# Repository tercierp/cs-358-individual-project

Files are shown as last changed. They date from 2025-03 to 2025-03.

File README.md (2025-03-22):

# 2D Plotter Project

## Overview
This project showcases the development of a **2D plotter**, a machine capable of drawing complex fractal patterns using **L-systems**. The plotter consists of two stepper motors controlling the X and Y axes, along with a servo motor to lift and lower the pen. The software is written in **C++ for Arduino UNO**, which controls the motors and processes L-system instructions to generate fractals.

The goal of this project was to design and build a fully functional **pen plotter** that can create intricate mathematical patterns on a piece of paper. This work highlights my expertise in **embedded systems, motion control, algorithmic drawing, and mechanical design**. 

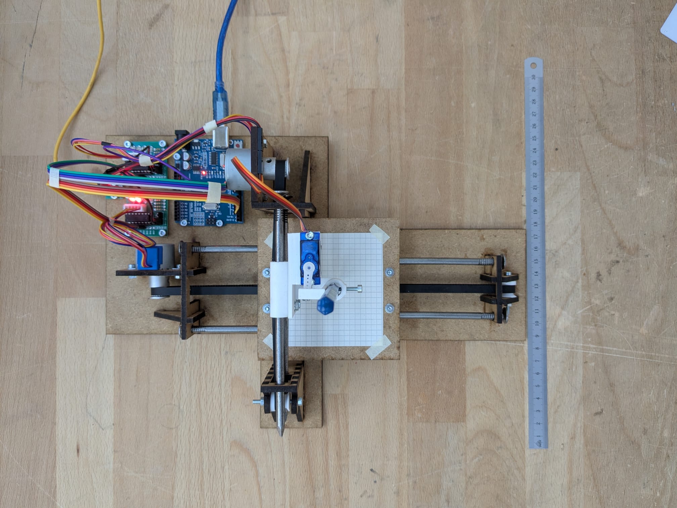
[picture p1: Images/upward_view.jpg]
Plotters

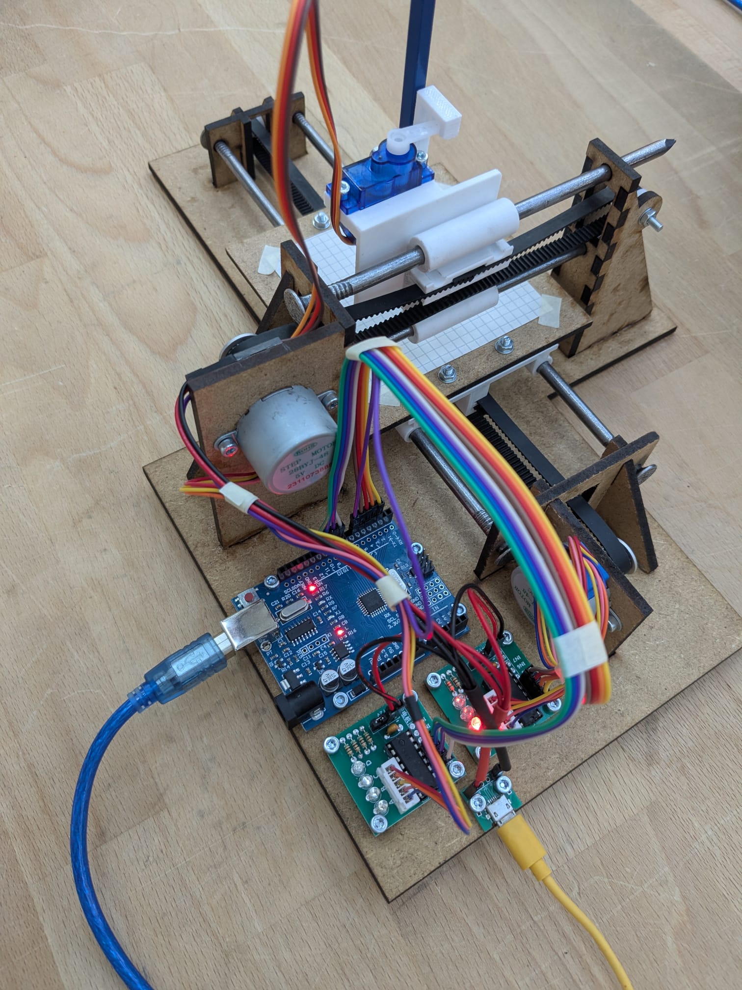
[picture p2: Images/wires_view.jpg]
wires


### Key Features
- **Stepper motors** for precise X-Y axis movement.
- **Servo motor** for lifting/lowering the pen.
- **Arduino UNO** for motor control.
- **L-System fractal generation** for drawing complex structures.
- **Laser-cut frame** for efficient manufacturing.
- **Pen holder 3D printing** for a precise design.

### Circuit
For good cable management, I created this circuit using Fritzing. For better understanding, the colors match the real cables in the pictures.
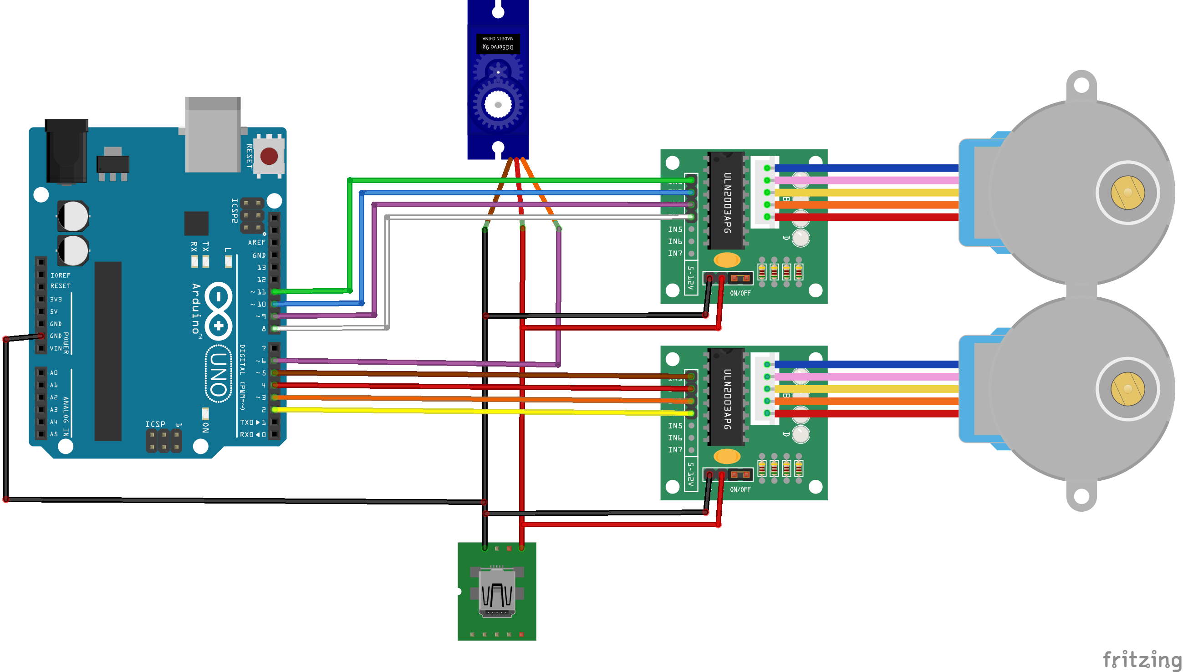
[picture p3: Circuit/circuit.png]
circuit


## Project Structure
### **Main code**
The core Arduino code for controlling the plotter is located in the **Code/** directory. This includes:
- circleinsidesquare.ino - Draw a circle and circle.
- L_System.ino - Implements L-system fractal parsing.
### **Debugging code**
- moveto.ino - Controls the position of the pen.
- servo.ino - Tests the positions of the servo.
- square.ino - Basic square.
- circle.ino - Basic circle.
- line.ino - Basic line.

## L-System Fractals
The plotter can generate various L-System fractals. Below are the corresponding input rules and parameters:
### Moore curve
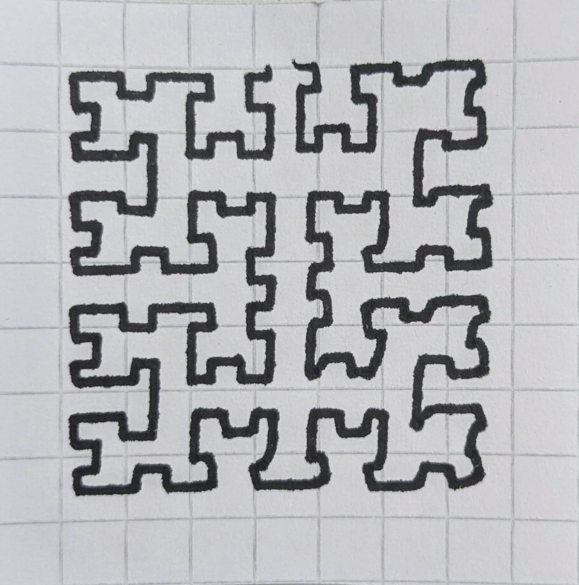
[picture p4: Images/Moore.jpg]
Moore curve

```
3;90;100;F;LFL+F+LFL;L=-RF+LFL+FR-;R=+LF-RFR-FL+
```
### Gosper curve
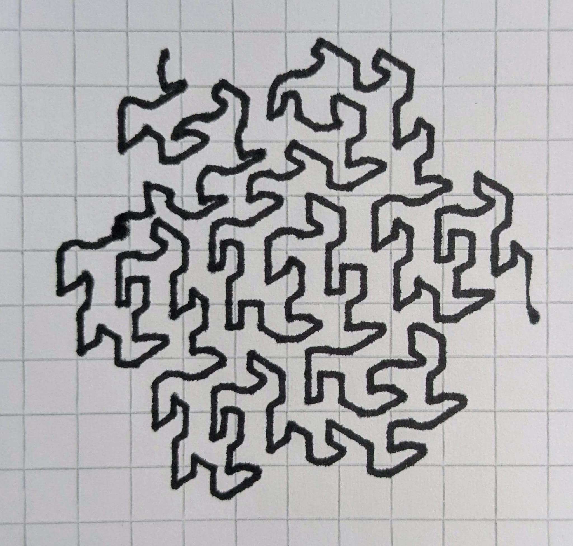
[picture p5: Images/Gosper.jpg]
Gosper curve

```
3;60;100;AB;A;A=A-B--B+A++AA+B-;B=+A-BB--B-A++A+B
```
### Dragon curve
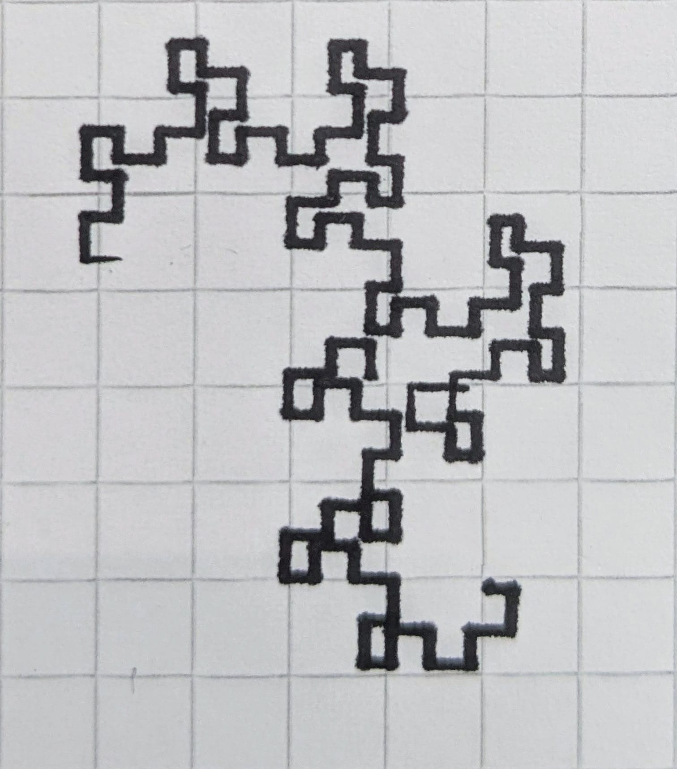
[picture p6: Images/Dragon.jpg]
Dragon curve

```
7;90;100;F;FA;A=A+BF+;B=-FA-B
```
### Koch curve
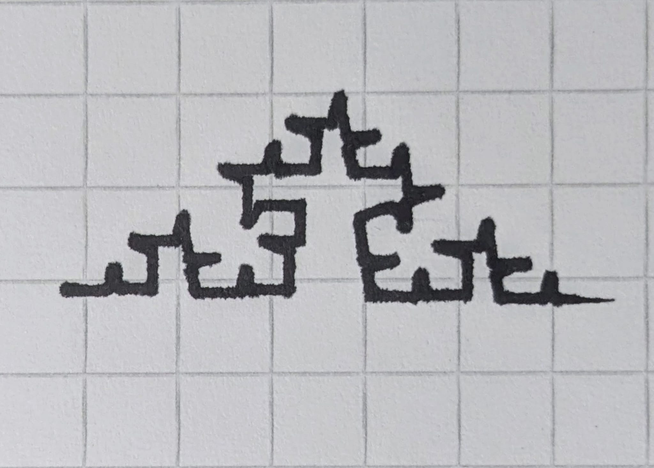
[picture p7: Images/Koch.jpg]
Koch

```
3;80;100;F;F;F=F+F--F+F;B=-FA-B
```
### Sierpinski Triangle
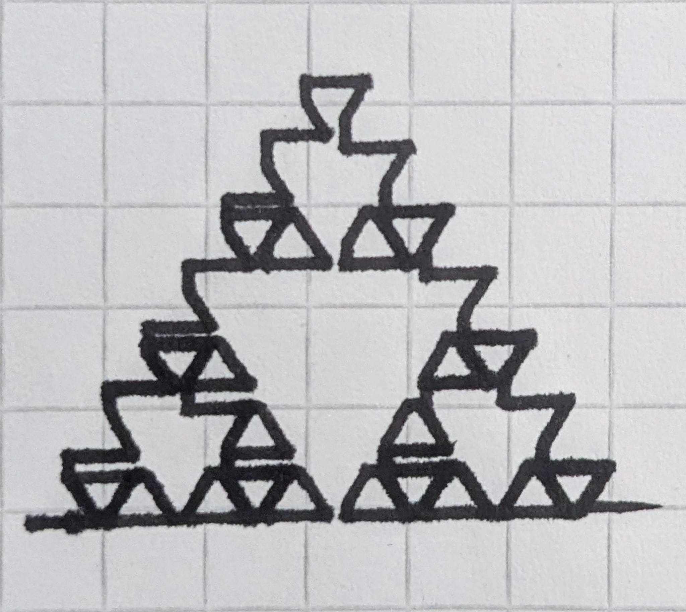
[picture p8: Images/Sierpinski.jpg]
Sierpinski Triangle

```
3;120;100;F;F;F=+F+F-F-F+F-
```

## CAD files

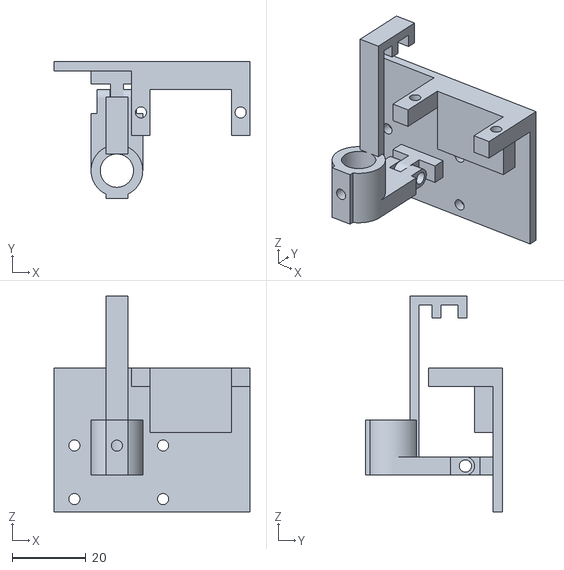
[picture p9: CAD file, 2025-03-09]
penholderv3.2.stl
53.0 x 37.0 x 58.5

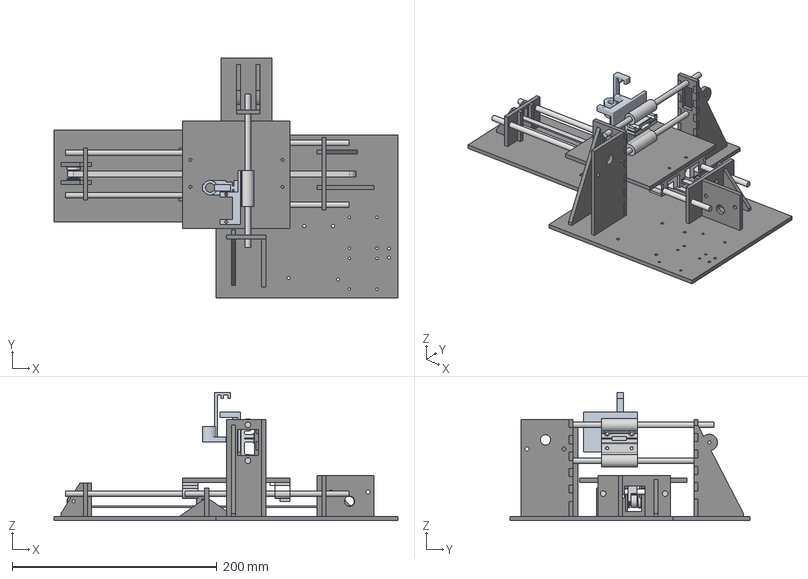
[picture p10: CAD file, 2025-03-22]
Plan_3D/2024-spring-2d-my-plotter.step
336.0 x 234.0 x 125.5 mm
TopRailHolder
BottomRailHolder
RightRailHolder
LeftRailHolder
MiddleHolder
PlateHolderNarrow
BasePlankNew
PenHolderSlider
Draw plate
Belt
PlateHolderWide
BlindPulley
Nails
part_object_id_1

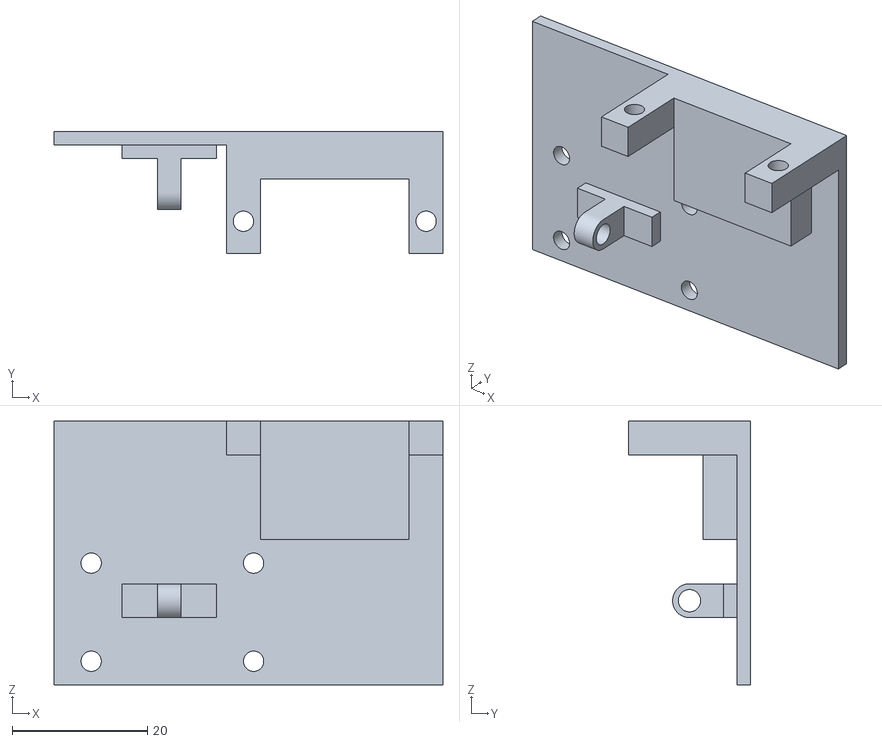
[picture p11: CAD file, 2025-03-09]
penholderv3.stl
57.5 x 18.0 x 39.0

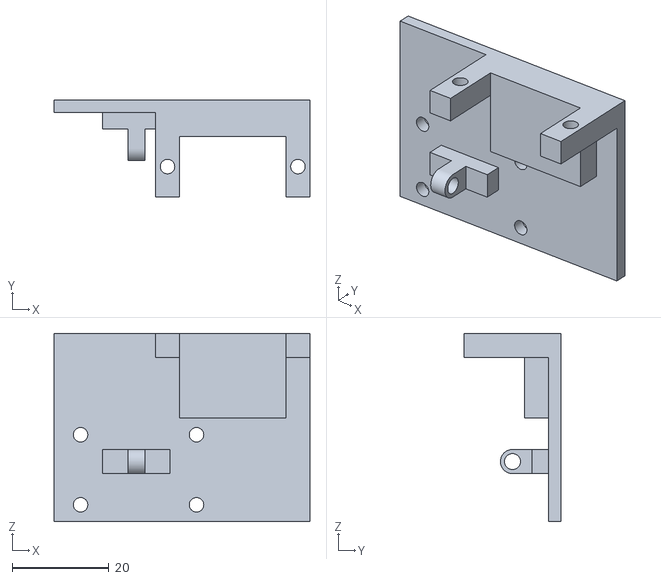
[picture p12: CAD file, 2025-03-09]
Plan_3D/penholder_back.stl
53.0 x 20.0 x 39.0

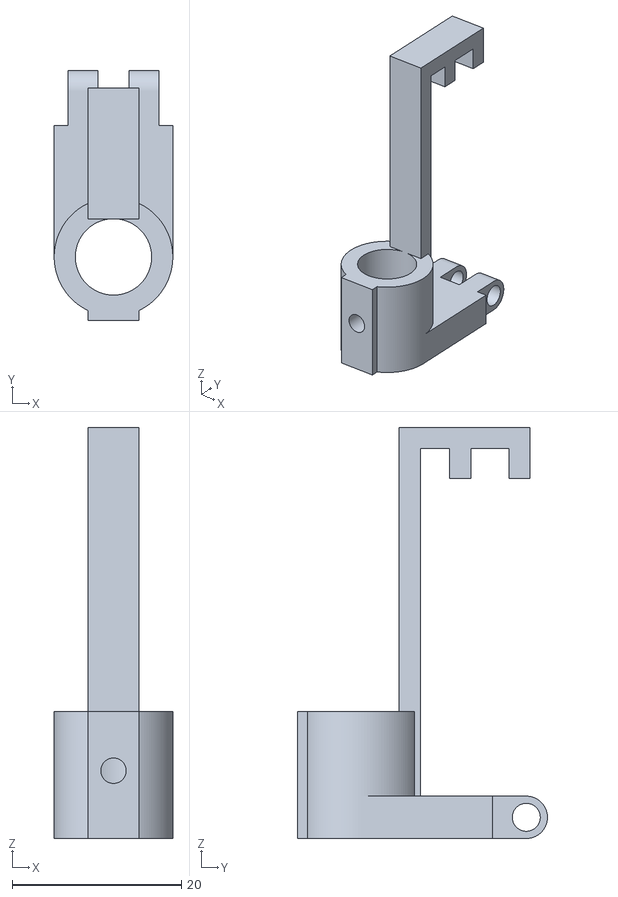
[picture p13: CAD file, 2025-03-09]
Plan_3D/penholder_front.stl
14.0 x 29.5 x 48.5

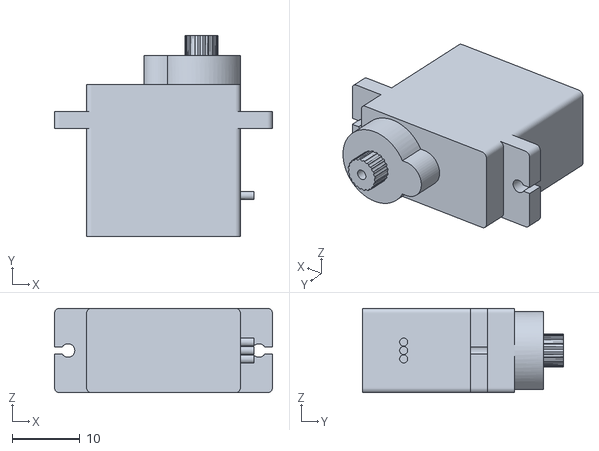
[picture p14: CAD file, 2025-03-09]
Plan_3D/stepper.stl
32.2 x 29.8 x 12.5

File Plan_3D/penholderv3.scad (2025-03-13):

$fn=128;
eps=0.01;
driftstepper=4.5;

//color("red") translate([41.5-driftstepper,-12.5/2-5,34]) rotate([-90,180,0]) import("stepper.stl", convexity=3);


module trou(d1,ep) {
    cylinder(h=ep+2*eps,d=d1,center=true);
}

module plot(ep) {
    translate([10.04,-ep,9.95]) difference() {
        union() {
             
            translate([0,-1,0])cube([14,5.5,5]);
            translate([7-3.5/2,-5,0]) cube([3.5,5+ep,5]);
            translate([7,-5,5/2]) rotate([90,0,90]) cylinder(h=3.5,d=5,center=true);
        
        
        }
        translate([7,-5,5/2]) rotate([90,0,90]) cylinder(h=3.5+2*eps,d=3.3,center=true);
    }
}

module plaque() {
    la = 57.5;
    lo = 39;
    ep = 2.5;
    av = 18;
    ls = 5;
    es = 5;
    motordeep=2;
    difference() {
        union() {
            cube([la-driftstepper,ep,lo]);
            translate([25.5-driftstepper,-av+0.5,lo-es]) cube([ls,av+motordeep,es]);
            translate([25.5+22+ls-driftstepper,-av+0.5,lo-es]) cube([ls,av+motordeep,es]);
            translate([30.5-driftstepper,-5,lo-17.5]) cube([22,7,17.5]);
            //color("green") translate([25.5+2.5,-12,33]) cube([27,1,1])
            plot(ep);
            
        }
        //trous
        translate([5.5,0,3.5]) translate([0,ep/2,0]) rotate([90,0,0])  trou(3,ep);
        translate([5.5+24.004,0,3.5]) translate([0,ep/2,0]) rotate([90,0,0])  trou(3,ep);
        translate([5.5+24.004,0,3.5+14.5]) translate([0,ep/2,0]) rotate([90,0,0])  trou(3,ep);
        translate([5.5,0,3.5+14.5]) translate([0,ep/2,0]) rotate([90,0,0])  trou(3,ep);
        translate([25.5+ls/2-driftstepper,-12.5/2-5,lo-es/2]) trou(3,es);
        translate([25.5+22+ls+ls/2-driftstepper,-12.5/2-5,lo-es/2]) trou(3,es);    
    }
}
//==============

module front(){
    //color("yellow")translate ([10,0,39])cube([1,1,motorh]);
    ox = 17;
    oy = -27;
    oz = 9.95;
    h = 48.5;
    m=11.45;
    platic=12.7;
    motorh=15.4;
    translate([ox,oy,oz]) union(){
        difference(){
            union() {
                
                translate ([0,0,7.5]) cylinder(h=15,d=14,center=true);
                translate ([-3,4.5,0])cube([6,2.5,h]);
                translate ([-3,-7.5,0])cube([6,2.5,15]);
                translate ([-7,0,0])cube([14,15.5,5]);
                //rotate([0,0,90])color("green")translate ([13.8,-12,43.5])cube([4,12.7,1.6]); 
                translate ([-3,4.5,h-2.5])cube([6,m+4,2.5]);
                translate ([-3,m+5+1,h-6])cube([6,2.5,4.5]);
                translate ([-3,m+5-6,h-6])cube([6,2.5,4.5]);
                
                
                
            difference() {
                union() {
             
                    translate([3.5+0.1-1.75,17-1-3,0]) cube([3.5,2.5+1+3,5]);
                    translate([3.5+0.1,2.5+17,5/2]) rotate([90,0,90]) cylinder(h=3.5,d=5,center=true);
        
        
                }
                translate([3.5+0.1,2.5+17,5/2]) rotate([90,0,90]) cylinder(h=3.5+2*eps,d=3.3,center=true);
            }
                
                
            difference() {
                union() {
                    translate([-3.5-0.1-1.75,17-1-3,0]) cube([3.5,2.5+1+3,5]);
                    translate([-3.5-0.1,2.5+17,5/2]) rotate([90,0,90]) cylinder(h=3.5,d=5,center=true);
        
                }
                translate([-3.5-0.1,2.5+17,5/2]) rotate([90,0,90]) cylinder(h=3.5+2*eps,d=3.3,center=true);
            }    
                
                }
            union() {  
                translate ([0,0,7.5]) cylinder(h=15+2*eps,d=9,center=true);
                translate ([0,-5,8])rotate([90,0,0])trou(3,5);
                
            }
        }
    }
}



front();
plaque(); 

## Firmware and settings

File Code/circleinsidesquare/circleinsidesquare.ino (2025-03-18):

#include <Servo.h>
#include <AccelStepper.h>
#include <MultiStepper.h>

#define MotorInterfaceType 4

// Servo setup
Servo servo;
int angle = 90;
int delta = 3;

// Define stepper motors with new pins
AccelStepper X(MotorInterfaceType, 2, 4, 3, 5);
AccelStepper Y(MotorInterfaceType, 8, 10, 9, 11);
MultiStepper XY;

// Position array for movement
long pos_xy[2] = {0, 0};

void setup() {
    // Initialize servo and set to initial (pen up) position
    servo.attach(6);
    penup(); // Ensure the pen starts in the up position

    // Set up stepper motors
    X.setMaxSpeed(400.0);
    Y.setMaxSpeed(400.0);
    XY.addStepper(X);
    XY.addStepper(Y);

    Serial.begin(9600);
    Serial.println("Enter square size:");
}

void loop() {
    penup(); // Keep pen up while waiting for input

    // Wait for serial input to get square size
    if (Serial.available()) {
        long squareSize = Serial.parseInt();
        
        Serial.print("Drawing square of size: ");
        Serial.println(squareSize);

        drawSquareThenCircle(squareSize);
        
        // Ensure pen stays up at the end of the drawing
        penup();
    }
}

void drawSquareThenCircle(long size) {
    // Lower the pen to begin drawing
    pendown();
    
    // Compute circle radius (circle fits perfectly inside the square)
    long radius = size / 2;

    // Get current position as the starting point
    long startX = X.currentPosition();
    long startY = Y.currentPosition();

    // Calculate the middle of the right side of the square (starting point)
    long midRightX = startX + size / 2;

    // Define square corners, starting from middle-right and ending back there
    long corners[5][2] = {
        {startX + size, startY},
        {startX + size, startY + size},
        {startX, startY + size},
        {startX, startY},
        {midRightX, startY}
    };

    for (int i = 0; i < 5; i++) {
        pos_xy[0] = corners[i][0];
        pos_xy[1] = corners[i][1];

        XY.moveTo(pos_xy);
        XY.runSpeedToPosition();  // Move to the next corner

        Serial.print("Moved to: X=");
        Serial.print(pos_xy[0]);
        Serial.print(" Y=");
        Serial.println(pos_xy[1]);
    }

    Serial.println("Square complete. Starting circle...");

    // Compute circle center (perfectly inside the square)
    long centerX = startX + radius;
    long centerY = startY + radius;

    // Draw the circle inside the square
    drawCircle(centerX, centerY, radius);

    // Lift the pen after drawing is complete
    penup();
    delay(10000000);
}

void drawCircle(long centerX, long centerY, long radius) {
    int steps = 400;  // More points means a smoother circle

    for (int i = 0; i <= steps; i++) {
        float angle_rad = (2 * PI * i) / steps - PI / 2;  // Calculate the angle in radians
        pos_xy[0] = centerX + (long)(radius * cos(angle_rad));
        pos_xy[1] = centerY + (long)(radius * sin(angle_rad));

        XY.moveTo(pos_xy);
        XY.runSpeedToPosition();  // Execute the movement

        Serial.print("Moved to: X=");
        Serial.print(pos_xy[0]);
        Serial.print(" Y=");
        Serial.println(pos_xy[1]);

        delay(50);  // Adjust delay for smoother movement
    }

    Serial.println("Circle complete.");
}

void penup() {
    // Lift the pen by setting the servo to a higher position
    servo.write(angle - delta);
    delay(500); // Delay to allow the servo to move
}

void pendown() {
    // Lower the pen by setting the servo to a lower position
    servo.write(angle + delta + 7);
    delay(500); // Delay to allow the servo to move
}

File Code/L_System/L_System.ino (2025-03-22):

#include <AccelStepper.h>
#include <MultiStepper.h>
#include <Servo.h>

#define MotorInterfaceType 4

// Stepper motor control for X and Y
AccelStepper X(MotorInterfaceType, 2, 4, 3, 5);
AccelStepper Y(MotorInterfaceType, 8, 10, 9, 11);
MultiStepper XY;

// Servo motor for pen control
Servo servo;
int penDownAngle = 100;
int penUpAngle = 87;

// Memory-efficient parameters
#define MAX_BUFFER 50
#define STACK_SIZE 15
#define MAX_RULES 5
#define MAX_RULE_LENGTH 30
#define MOTOR_SPEED 400

char alphabet[10] = {0};
char axiom[30] = {0};
char rules[MAX_RULES][MAX_RULE_LENGTH] = {{0}};
int depth = 0, angle = 0;
float scale = 100.0;

// Turtle State
float posX = 0, posY = 0;
float dir = 0; // Persistent direction
long pos_xy[2] = {0, 0};

// Stack for push/pop operations
struct State {
    float x, y, direction;
};
State stack[STACK_SIZE];
int stackIndex = 0;

void parseInput(char *input) {
    char *token;
    int ruleIndex = 0;

    // Serial.println("\n[DEBUG] Parsing Input...");
    token = strtok(input, ";");
    if (token) depth = atoi(token);
    token = strtok(NULL, ";");
    if (token) angle = atoi(token);
    token = strtok(NULL, ";");
    if (token) scale = atof(token);
    token = strtok(NULL, ";");
    if (token) strncpy(alphabet, token, sizeof(alphabet) - 1);
    token = strtok(NULL, ";");
    if (token) strncpy(axiom, token, sizeof(axiom) - 1);

    memset(rules, 0, sizeof(rules));
    while ((token = strtok(NULL, ";")) && ruleIndex < MAX_RULES) {
        if (strlen(token) > 2 && token[1] == '=') {
            strncpy(rules[ruleIndex], token, MAX_RULE_LENGTH - 1);
            ruleIndex++;
        }
    }
}


void moveTo(float x, float y, bool draw) {
    //Serial.print("[DEBUG] Moving to: (");
    //Serial.print(x);
    //Serial.print(", ");
    //Serial.print(y);
    //Serial.print(") with pen ");
    //Serial.println(draw ? "DOWN" : "UP");

    pos_xy[0] = (long)x;
    pos_xy[1] = (long)y;

    servo.write(draw ? penDownAngle : penUpAngle);
    XY.moveTo(pos_xy);
    XY.runSpeedToPosition();
    delay(100);
}

void computeAndDrawLSystem(const char *instructions, int index) {
    if (instructions[index] == '\0') {
        return;  // Base case: Stop when reaching the end of the string
    }

    char cmd = instructions[index];

    if (cmd == '+') {  
        dir += angle;
        Serial.print("[DEBUG] Turning +");
        Serial.print(angle);
        Serial.println(" degrees");
    } 
    else if (cmd == '-') {
        dir -= angle;
        Serial.print("[DEBUG] Turning -");
        Serial.print(angle);
        Serial.println(" degrees");
    } 
    else if (strchr(alphabet, cmd) != NULL) {  // If it's a drawable character
        float newX = posX + cos(radians(dir)) * scale;
        float newY = posY + sin(radians(dir)) * scale;

        Serial.print("[DEBUG] Moving to: (");
        Serial.print(newX);
        Serial.print(", ");
        Serial.print(newY);
        Serial.println(") with pen DOWN");

        moveTo(newX, newY, true);
        posX = newX;
        posY = newY;
    } 
    else if (cmd == '[') {
        if (stackIndex < STACK_SIZE) {
            stack[stackIndex++] = {posX, posY, dir};
            Serial.println("[DEBUG] Pushing state to stack.");
        }
    } 
    else if (cmd == ']') {
        if (stackIndex > 0) {
            stackIndex--;
            posX = stack[stackIndex].x;
            posY = stack[stackIndex].y;
            dir = stack[stackIndex].direction;

            Serial.println("[DEBUG] Popping state from stack.");
            moveTo(posX, posY, false);
        }
    }

    // Recursive call for the next character
    computeAndDrawLSystem(instructions, index + 1);
}

void iterativeExpandAndDraw() {
    // Serial.println("\n[DEBUG] Starting Streamed Recursive Drawing...");
    // Serial.print("[DEBUG] Axiom: ");
    // Serial.println(axiom);

    for (int i = 0; axiom[i] != '\0'; i++) {
        Serial.print("[EXPAND] ");
        Serial.println(axiom[i]);
        expandAndDraw(axiom[i], depth);
    }

    Serial.println("[DEBUG] Finished Drawing. Lifting pen...");
    servo.write(penUpAngle);
    delay(1000000);
}



void expandAndDraw(char symbol, int currentDepth) {
    if (currentDepth > 0) {
        for (int i = 0; i < MAX_RULES; i++) {
            if (rules[i][0] == symbol && rules[i][1] == '=') {
                const char* expansion = rules[i] + 2;
                for (int j = 0; expansion[j] != '\0'; j++) {
                    expandAndDraw(expansion[j], currentDepth - 1);
                }
                return;
            }
        }
    }

    if (symbol == '+') {
        dir += angle;
        // Serial.print("[DEBUG] Turning +"); Serial.println(angle);
    } 
    else if (symbol == '-') {
        dir -= angle;
        // Serial.print("[DEBUG] Turning -"); Serial.println(angle);
    } 
    else if (symbol == '[') {
        if (stackIndex < STACK_SIZE) {
            stack[stackIndex++] = {posX, posY, dir};
            // Serial.println("[DEBUG] Pushing state to stack.");
        }
    } 
    else if (symbol == ']') {
        if (stackIndex > 0) {
            stackIndex--;
            posX = stack[stackIndex].x;
            posY = stack[stackIndex].y;
            dir = stack[stackIndex].direction;
            moveTo(posX, posY, false);
            // Serial.println("[DEBUG] Popping state from stack.");
        }
    } 
    else if (strchr(alphabet, symbol) != NULL) {
        float newX = posX + cos(radians(dir)) * scale;
        float newY = posY + sin(radians(dir)) * scale;

        moveTo(newX, newY, true);
        posX = newX;
        posY = newY;

        Serial.print("[POSITION] ");
        Serial.print(posX);
        Serial.print(", ");
        Serial.println(posY);
    }
}




/**
 * Setup function - Initializes motors and serial communication.
 */
void setup() {
    delay(1000);
    Serial.begin(115200);

    X.setMaxSpeed(MOTOR_SPEED);
    Y.setMaxSpeed(MOTOR_SPEED);
    XY.addStepper(X);
    XY.addStepper(Y);

    servo.attach(6);
    servo.write(penUpAngle);

    Serial.println("\nArduino Ready! Enter L-System parameters:");
}

/**
 * Loop function - Receives input and processes L-System instructions.
 */
void loop() {
    if (Serial.available()) {
        char inputBuffer[100];
        int bytesRead = Serial.readBytesUntil('\n', inputBuffer, sizeof(inputBuffer) - 1);
        inputBuffer[bytesRead] = '\0';

        parseInput(inputBuffer);
        iterativeExpandAndDraw();
    }
}

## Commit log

2025-03-09 Add lot of code for the printer and some designed pieces
    [back_penholderv3.stl, front_penholderv3.stl, penholderv3.2.stl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]
2025-03-09 Stepper code for the tests and the L-language as the final code
2025-03-13 Change the pins for better cable managment fix some memory problems
    [penholderv3.scad]
2025-03-18 Correct the pins and add the up and down pen function
    [circleinsidesquare.ino]
2025-03-18 Better structure the project
    [penholder_back.stl, penholder_front.stl, penholder_old.stl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]
2025-03-22 feat(draw): add the L-System
    [2024-spring-2d-my-plotter.step, penholder_back.stl, penholder_front.stl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]
